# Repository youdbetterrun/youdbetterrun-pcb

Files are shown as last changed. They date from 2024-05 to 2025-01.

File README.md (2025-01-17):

# You'd Better Run!

Lets you know if you can walk leisurely to catch the bus, or if you'd better run.

Image of the completed project hanging on the wall

This repository holds the printed circuit board design files. A render of the PCB is below.

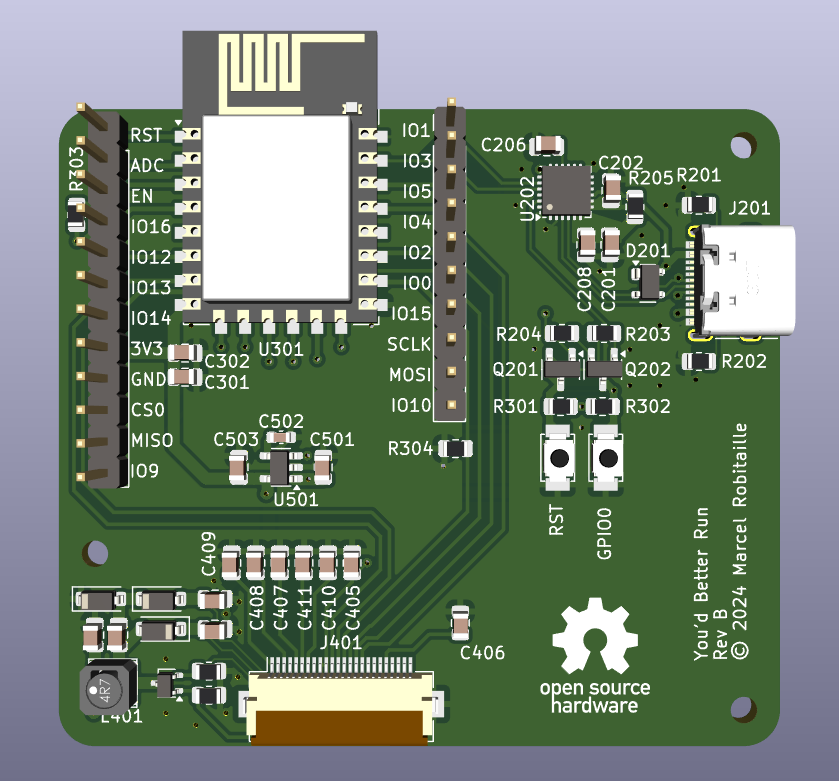
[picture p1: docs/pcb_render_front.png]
3D render of the PCB


There are separate repositories for the firmware and 3D models.
- [Firmware](https://github.com/youdbetterrun/youdbetterrun-firmware): The code that runs on the microcontroller.
- [3D](https://github.com/youdbetterrun/youdbetterrun-3d): 3D models that need to be 3D printed and assembly instructions.

[Blog post about this project.](https://blog.marcelrobitaille.me/youdbetterrun/)

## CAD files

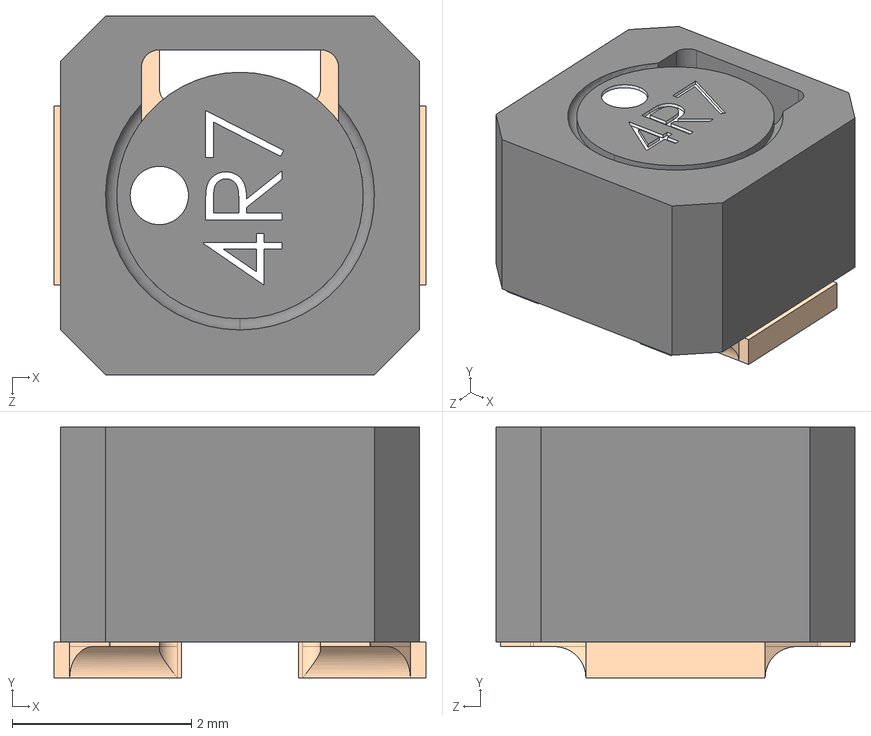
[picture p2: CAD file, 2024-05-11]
3d/VLCF4028T-471MR14-2.stp
4.15 x 2.80 x 4.00 mm

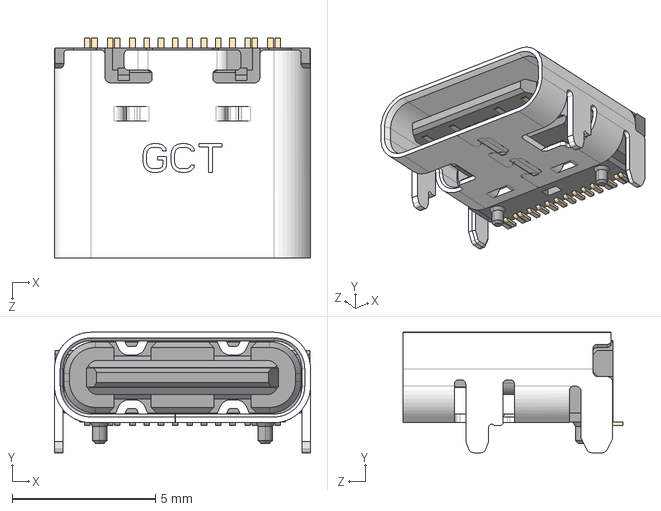
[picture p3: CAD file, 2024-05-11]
3d/USB4105-GF-A.stp
8.94 x 4.21 x 7.70 mm
HSG_默认

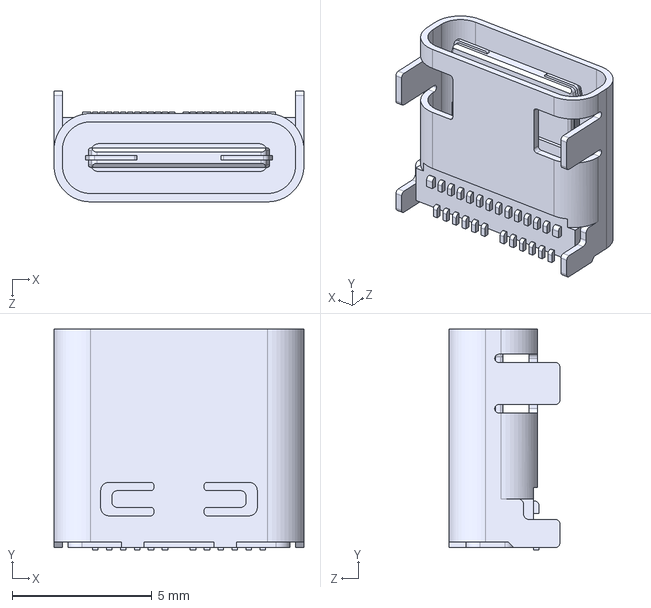
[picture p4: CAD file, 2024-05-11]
3d/105450-0101.stp
8.94 x 7.90 x 3.96 mm

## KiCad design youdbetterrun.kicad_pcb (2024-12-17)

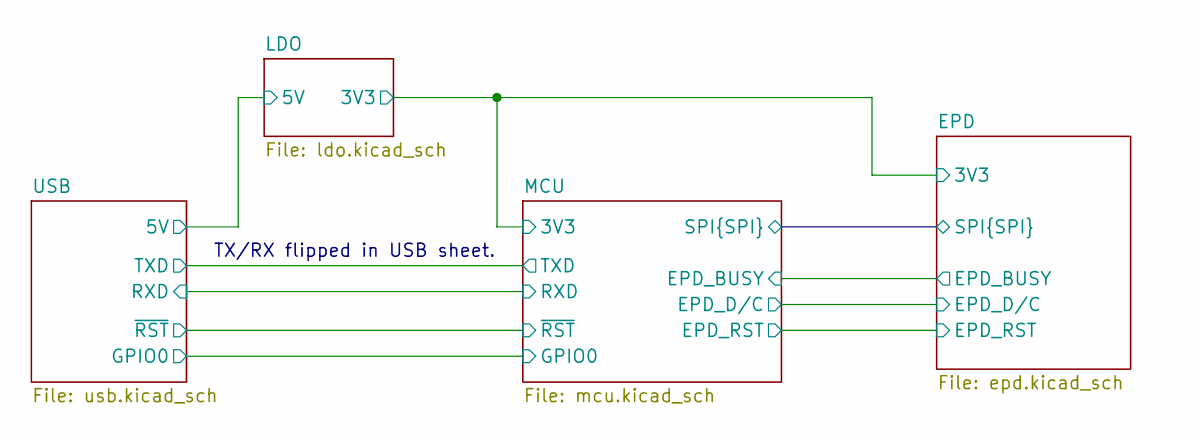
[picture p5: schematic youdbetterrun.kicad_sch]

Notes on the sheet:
TX/RX flipped in USB sheet.

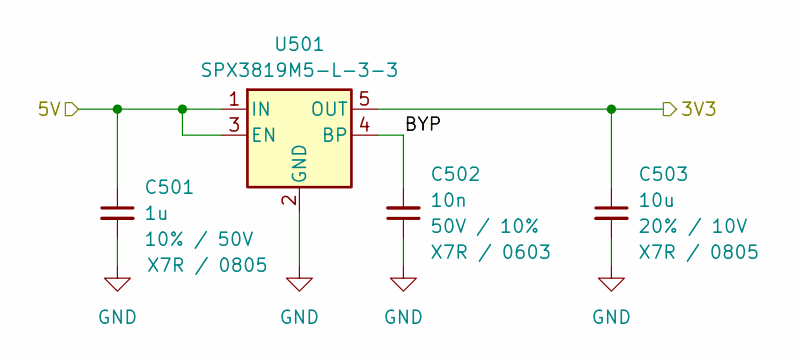
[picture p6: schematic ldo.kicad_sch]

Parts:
C501: 1u; C_0805_2012Metric; Tolerance 10%; Rated Voltage 50V; MPN CC0805KKX7R9BB105; LCSC Part Number C91185
C502: 10n; C_0603_1608Metric; Rated Voltage 50V; Tolerance 10%; MPN CC0603KRX7R9BB103; LCSC Part Number C100042
C503: 10u; C_0805_2012Metric; Rated Voltage 10V; Tolerance 20%; MPN CS2012X7R106M100NRE; LCSC Part Number C5189822
U501: SPX3819M5-L-3-3; SOT-23-5; MPN SPX3819M5-L-3-3/TR; LCSC Part Number C9055

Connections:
/EPD/3V3: C503.1, U501.5 (OUT); also elsewhere on the board
/LDO/BYP: C502.2, U501.4 (BP)
/USB/5V: C501.1, U501.1 (IN), U501.3 (EN); also elsewhere on the board
GND: C501.2, C502.1, C503.2, U501.2 (GND); also elsewhere on the board

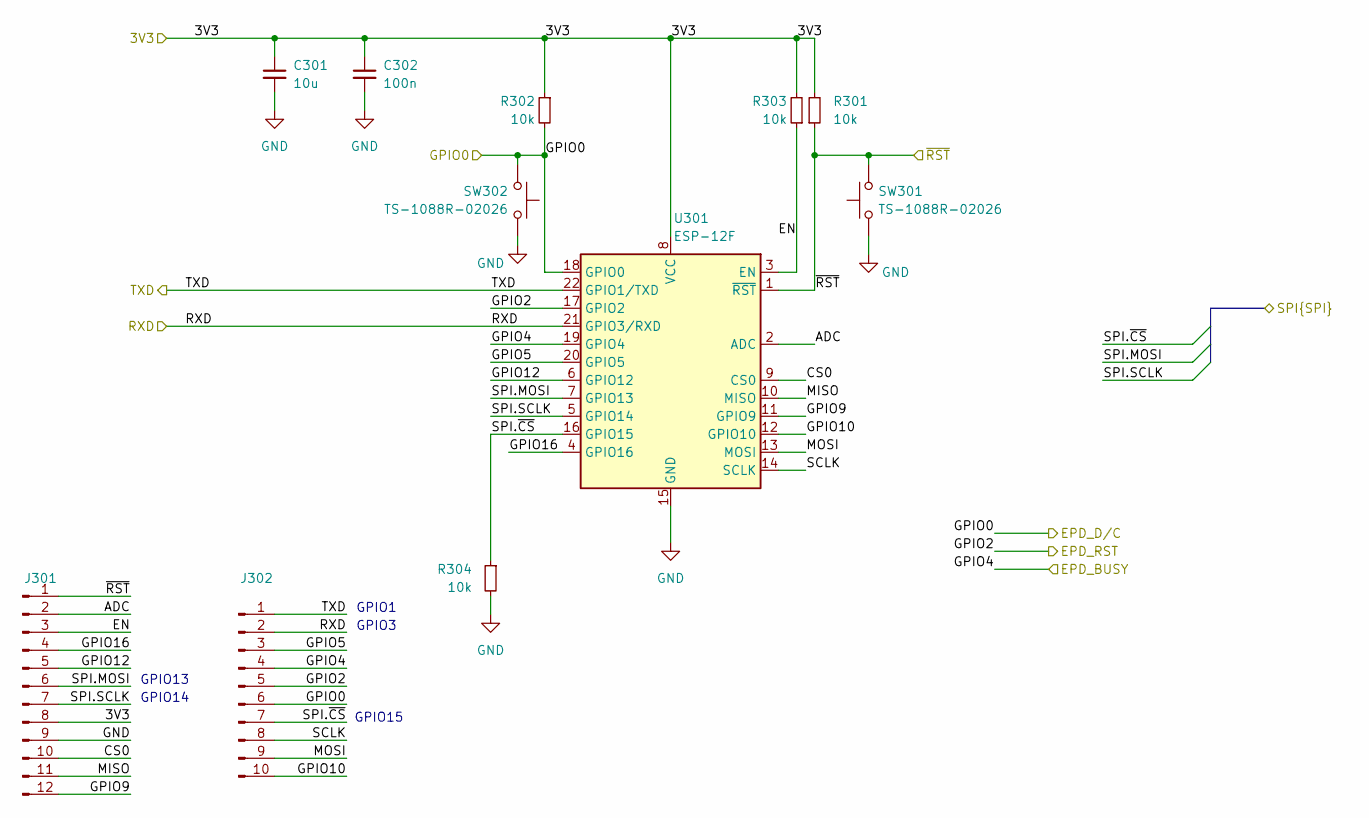
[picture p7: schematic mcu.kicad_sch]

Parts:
C301: 10u; C_0805_2012Metric; Rated Voltage 10V; Tolerance 20%; MPN CS2012X7R106M100NRE; LCSC Part Number C5189822
C302: 100n; C_0805_2012Metric; Rated Voltage 50V; Tolerance 10%; MPN 0805B104K500NT; LCSC Part Number C38141
J301: Conn_01x05_Pin; PinHeader_1x12_P2.54mm_Vertical
J302: Conn_01x10_Pin; PinHeader_1x10_P2.54mm_Vertical
R301, R302, R303, R304: 10k; R_0805_2012Metric; Tolerance 1%; MPN 0805W8F1002T5E; LCSC Part Number C17414
SW301, SW302: TS-1088R-02026; TS-1088R-02026_SW_SMD_3x4mm; MPN TS-1088R-02026; LCSC Part Number C455280
U301: ESP-12F; ESP-12E; MPN ESP-12F(ESP8266MOD); LCSC Part Number C82891

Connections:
/EPD/3V3: C301.1, C302.1, J301.8, R301.2, R302.1, R303.2, U301.8 (VCC); also elsewhere on the board
/EPD/EPD_BUSY: J302.4, U301.19 (GPIO4); also elsewhere on the board
/EPD/EPD_D/C: J302.6, R302.2, SW302.2, U301.18 (GPIO0); also elsewhere on the board
/EPD/EPD_RST: J302.5, U301.17 (GPIO2); also elsewhere on the board
/EPD/SPI.MOSI: J301.6, U301.7 (GPIO13); also elsewhere on the board
/EPD/SPI.SCLK: J301.7, U301.5 (GPIO14); also elsewhere on the board
/EPD/SPI.~CS: J302.7, R304.1, U301.16 (GPIO15); also elsewhere on the board
/MCU/ADC: J301.2, U301.2 (ADC)
/MCU/CS0: J301.10, U301.9 (CS0)
/MCU/EN: J301.3, R303.1, U301.3 (EN)
/MCU/GPIO5: J302.3, U301.20 (GPIO5)
/MCU/GPIO9: J301.12, U301.11 (GPIO9)
/MCU/GPIO10: J302.10, U301.12 (GPIO10)
/MCU/GPIO12: J301.5, U301.6 (GPIO12)
/MCU/GPIO16: J301.4, U301.4 (GPIO16)
/MCU/MISO: J301.11, U301.10 (MISO)
/MCU/MOSI: J302.9, U301.13 (MOSI)
/MCU/RXD: J302.2, U301.21 (GPIO3/RXD); also elsewhere on the board
/MCU/SCLK: J302.8, U301.14 (SCLK)
/MCU/TXD: J302.1, U301.22 (GPIO1/TXD); also elsewhere on the board
/MCU/~RST: J301.1, R301.1, SW301.2, U301.1 (~RST); also elsewhere on the board
GND: C301.2, C302.2, J301.9, R304.2, SW301.1, SW302.1, U301.15 (GND); also elsewhere on the board

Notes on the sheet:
GPIO13
GPIO15
GPIO1
GPIO14
GPIO3

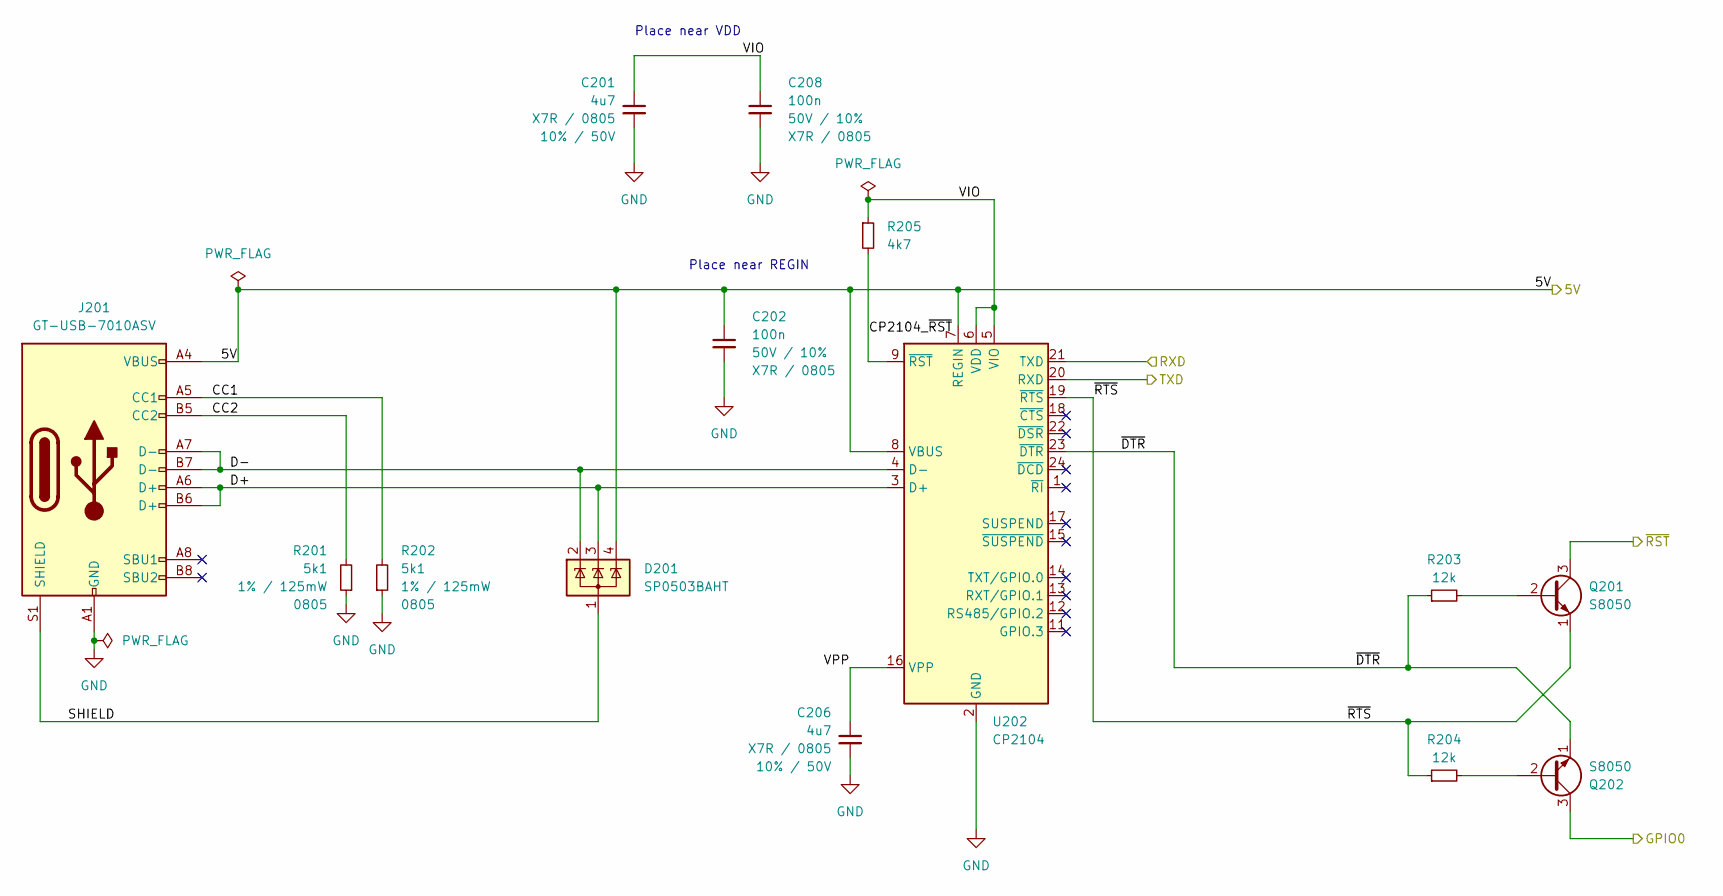
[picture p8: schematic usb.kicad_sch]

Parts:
C201, C206: 4u7; C_0805_2012Metric; Rated Voltage 50V; Tolerance 10%; MPN CL21A475KBQNNNE; LCSC Part Number C98192
C202, C208: 100n; C_0805_2012Metric; Rated Voltage 50V; Tolerance 10%; MPN 0805B104K500NT; LCSC Part Number C38141
D201: SP0503BAHT; SOT-143; MPN SP0503BAHTG; LCSC Part Number C7074
J201: GT-USB-7010ASV; USB_C_Receptacle_G-Switch_GT-USB-7010ASV; MPN G-Switch; LCSC Part Number C2988369
Q201, Q202: S8050; SOT-23-3; MPN S8050; LCSC Part Number C2891804
R201, R202: 5k1; R_0805_2012Metric; Tolerance 1%; MPN 0805W8F5101T5E; LCSC Part Number C27834
R203, R204: 12k; R_0805_2012Metric; Tolerance 1%; MPN 0805W8F1202T5E; LCSC Part Number C17444
R205: 4k7; R_0805_2012Metric; MPN 0805W8F4701T5E; LCSC Part Number C17673
U202: CP2104; QFN-24-1EP_4x4mm_P0.5mm_EP2.6x2.6mm; MPN CP2104-F03-GMR; LCSC Part Number C47742

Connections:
/EPD/EPD_D/C: Q202.3 (C); also elsewhere on the board
/MCU/RXD: U202.21 (TXD); also elsewhere on the board
/MCU/TXD: U202.20 (RXD); also elsewhere on the board
/MCU/~RST: Q201.3 (C); also elsewhere on the board
/USB/5V: C202.1, D201.4 (K), J201.A4 (VBUS), J201.A9 (VBUS), J201.B4 (VBUS), J201.B9 (VBUS), U202.7 (REGIN), U202.8 (VBUS); also elsewhere on the board
/USB/CC1: J201.A5 (CC1), R202.2
/USB/CC2: J201.B5 (CC2), R201.2
/USB/CP2104_~RST: R205.2, U202.9 (~RST)
/USB/D+: D201.3 (K), J201.A6 (D+), J201.B6 (D+), U202.3 (D+)
/USB/D-: D201.2 (K), J201.A7 (D-), J201.B7 (D-), U202.4 (D-)
/USB/SHIELD: D201.1 (A), J201.S1 (SHIELD)
/USB/VIO: C201.1, C208.1, R205.1, U202.5 (VIO), U202.6 (VDD)
/USB/VPP: C206.1, U202.16 (VPP)
/USB/~DTR: Q202.1 (E), R203.1, U202.23 (~DTR)
/USB/~RTS: Q201.1 (E), R204.1, U202.19 (~RTS)
GND: C201.2, C202.2, C206.2, C208.2, J201.A1 (GND), J201.A12 (GND), J201.B1 (GND), J201.B12 (GND), R201.1, R202.1, U202.2 (GND), U202.25 (GND); also elsewhere on the board
unnamed: Q201.2 (B), R203.2
unnamed: Q202.2 (B), R204.2

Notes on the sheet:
Place near VDD
Place near REGIN

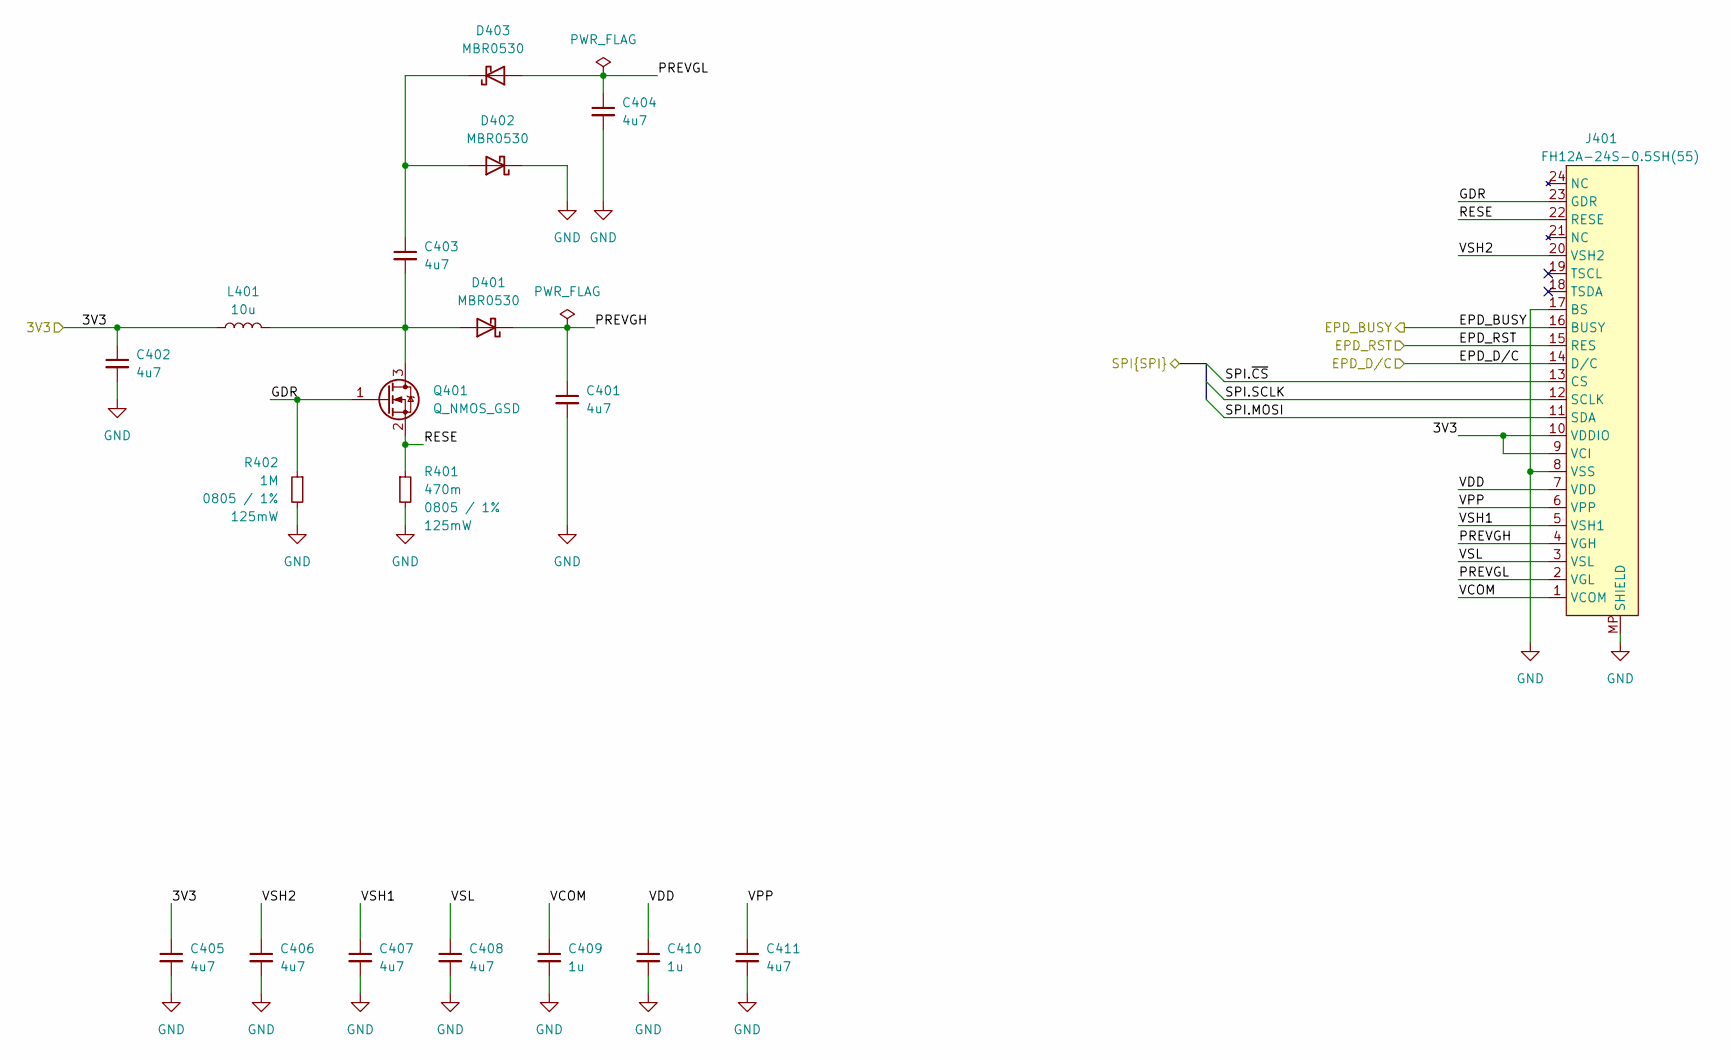
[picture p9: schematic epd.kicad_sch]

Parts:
C401, C402, C403, C404, C405, C406, C407, C408, C411: 4u7; C_0805_2012Metric; Tolerance 10%; Rated Voltage 50V; MPN CL21A475KBQNNNE; LCSC Part Number C98192
C409, C410: 1u; C_0805_2012Metric; Tolerance 10%; Rated Voltage 50V; MPN CC0805KKX7R9BB105; LCSC Part Number C91185
D401, D402, D403: MBR0530; D_SOD-123; MPN MBR0530; LCSC Part Number C77336
J401: FH12A-24S-0.5SH(55); Hirose_FH12-24S-0.5SH_1x24-1MP_P0.50mm_Horizontal; MPN FH12A-24S-0.5SH(55); LCSC Part Number C506794
L401: 10u; L_4x4x2.6; MPN YJYCOIN YNR4026-100M; LCSC Part Number C497803
Q401: Q_NMOS_GSD; SOT-323_SC-70; MPN SI1308EDL-T1-GE3; LCSC Part Number C469327
R401: 470m; R_0805_2012Metric; Tolerance 1%; MPN 0805W8F470LT5E; LCSC Part Number C25040
R402: 1M; R_0805_2012Metric; Tolerance 1%; MPN 0805W8F1004T5E; LCSC Part Number C17514

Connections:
/EPD/3V3: C402.1, C405.1, J401.9 (VCI), J401.10 (VDDIO), L401.1; also elsewhere on the board
/EPD/EPD_BUSY: J401.16 (BUSY); also elsewhere on the board
/EPD/EPD_D/C: J401.14 (D/C); also elsewhere on the board
/EPD/EPD_RST: J401.15 (RES); also elsewhere on the board
/EPD/GDR: J401.23 (GDR), Q401.1 (G), R402.1
/EPD/PREVGH: C401.1, D401.1 (K), J401.4 (VGH)
/EPD/PREVGL: C404.1, D403.2 (A), J401.2 (VGL)
/EPD/RESE: J401.22 (RESE), Q401.2 (S), R401.1
/EPD/SPI.MOSI: J401.11 (SDA); also elsewhere on the board
/EPD/SPI.SCLK: J401.12 (SCLK); also elsewhere on the board
/EPD/SPI.~CS: J401.13 (CS); also elsewhere on the board
/EPD/VCOM: C409.1, J401.1 (VCOM)
/EPD/VDD: C410.1, J401.7 (VDD)
/EPD/VPP: C411.1, J401.6 (VPP)
/EPD/VSH1: C407.1, J401.5 (VSH1)
/EPD/VSH2: C406.1, J401.20 (VSH2)
/EPD/VSL: C408.1, J401.3 (VSL)
GND: C401.2, C402.2, C404.2, C405.2, C406.2, C407.2, C408.2, C409.2, C410.2, C411.2, D402.1 (K), J401.8 (VSS), J401.17 (BS), J401.MP (SHIELD), R401.2, R402.2; also elsewhere on the board
unnamed: C403.2, D401.2 (A), L401.2, Q401.3 (D)
unnamed: C403.1, D402.2 (A), D403.1 (K)

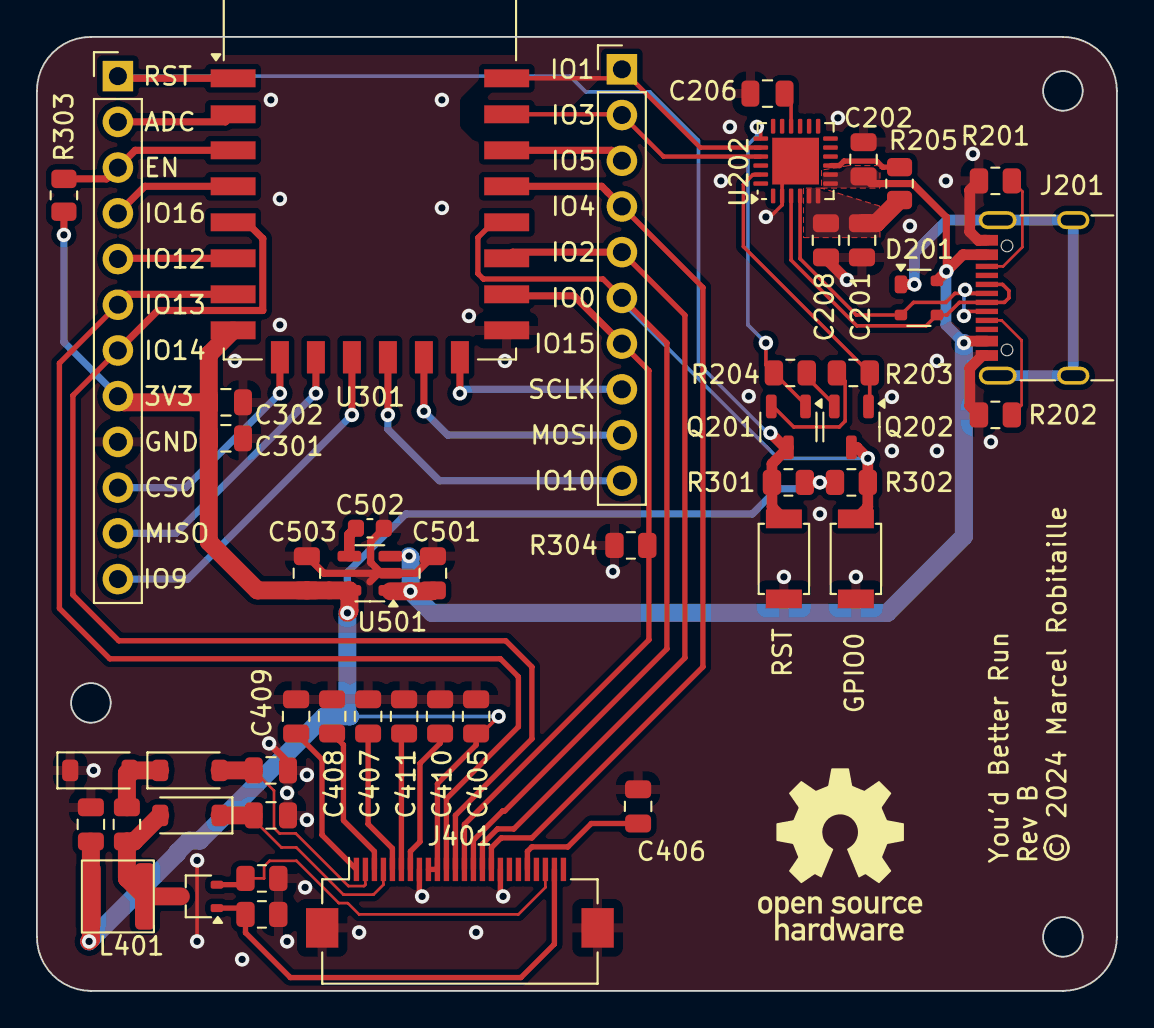
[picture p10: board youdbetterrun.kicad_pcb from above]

Board: 4 copper layers, 60.0 x 53.0 mm, 48 parts (0 on the bottom side), 48 nets.

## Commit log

2024-03-10 Remove CH340G
    [busbuddy.kicad_pcb, usb.kicad_sch]
2024-05-11 Switch to 16 pin USB-C
    [105450-0101.stp, USB4105-GF-A.stp, VLCF4028T-471MR14-2.stp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]
2024-05-11 Correct SPI pinout
    [busbuddy.kicad_pcb, busbuddy.kicad_sch, epd.kicad_sch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]
2024-05-26 Finish everything
    [busbuddy.kicad_pcb, busbuddy.kicad_sch, epd.kicad_sch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]
2024-12-17 Rename project
    Damn squatters
    [epd.kicad_sch, ldo.kicad_sch, mcu.kicad_sch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]
2024-12-17 Add OSHW logo
    [youdbetterrun.kicad_pcb]

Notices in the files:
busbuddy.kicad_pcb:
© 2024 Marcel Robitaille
